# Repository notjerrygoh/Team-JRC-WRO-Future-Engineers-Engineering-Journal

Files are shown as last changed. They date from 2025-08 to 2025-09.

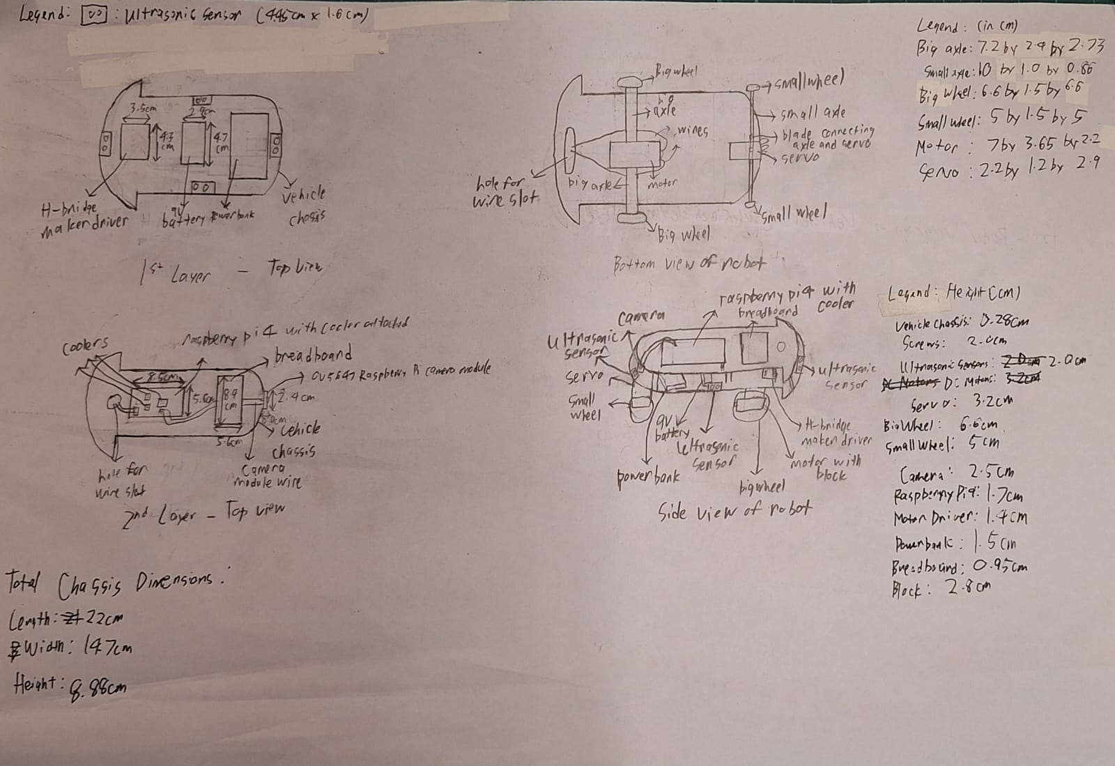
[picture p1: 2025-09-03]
mobility-management/Team JRC Robot Mechanical Diagram.jpeg

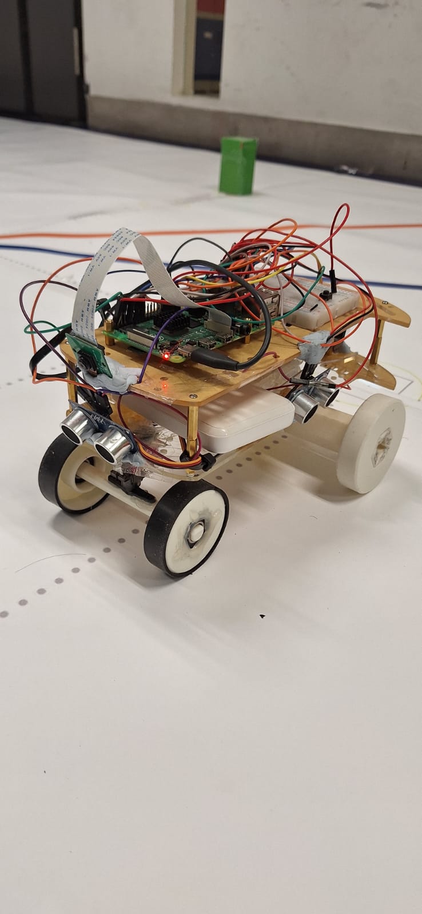
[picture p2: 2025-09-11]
v-photos/JRC's vehicle.jpeg

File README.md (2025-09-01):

Team JRC's Engineering Journal
====

Hello! We are team JRC, consisting of Jeremiah, Colin and Rey from Ngee Ann Polytechnic. We are participating in the World Robot Olympiad (WRO) Future Engineers competition in the season 2025. This repository contains engineering materials of the automated vehicle's model, as well as our engineering journal, where we document our experiences and the engineering design process even as we design and build our robot.

## Content

* `t-photos` contains 2 photos of the team (an official one and one funny photo with all team members)
* `v-photos` contains 6 photos of the vehicle (from every side, from top and bottom)
* `video` contains the video.md file with the link to a video where driving demonstration exists
* `schemes` contains one or several schematic diagrams in form of JPEG, PNG or PDF of the electromechanical components illustrating all the elements (electronic components and motors) used in the vehicle and how they connect to each other.
* `src` contains code of control software for all components which were programmed to participate in the competition
* `models` is for the files for models used by 3D printers, laser cutting machines and CNC machines to produce the vehicle elements. If there is nothing to add to this location, the directory can be removed.
* `mobility-management` contains the discussion for mobility management on how the motors are selected and implemented into our vehicle, as well as the vehicle chassis design selection and how the components are mounted onto the vehicle.
* `power-and-sense-management` contains the discussion for power and sense management on how the different power supply sources, as well as the sensors to detect objects are selected and implemented into our vehicle.
* `obstacle-management` contains the discussion for obstacle management on the vehicle's logic when it comes to avoiding obstacles and parking, and contains files of the pseudocode.
* `other` is for other files which can be used to understand how to prepare the vehicle for the competition. It may include documentation how to connect to a SBC/SBM and upload files there, datasets, hardware specifications, communication protocols descriptions etc. If there is nothing to add to this location, the directory can be removed.

## Introduction
The code consists of the following segments:
1. Colour Detection
2. Servo Movement
3. DC motor movement
4. Object detection
5. Line detection
6. Parking

### Basic functions
#### Colour detection
The robot will detect the colours by the Pi camera that is attached to the Raspberry Pi. It does this by first giving it a predefined upper and lower limit of values in HSV (Hue, Saturation, Value) so that the Pi camera can use these values to create a range and eventually a mask to help detect the colours when given a frame captured.

#### Servo movement
The servo will move by using PWM by sending a signal through the connected GPIO pin. The servo, given the PWM value, would turn in either the clockwise and anticlockwise direction from the starting position.

#### DC motor Movement
The DC Motor uses a motor driver to drive the DC Motor with an external power supply (9V battery) as the 5V from the Raspberry Pi is not enough to sustain it. We will connect the motor driver to 2 pins, 23 and 24. GPIO pins 23 and 24 connect to M1A and M1B respectively, allowing the robot to move forwards and backwards given values entered into the code.

### Applications
#### Object Detection
This applications combines the colour detection with the servo movement. When the Pi Camera approaches the red or green block on the map, it will detect the colour of the incoming block by the Pi Camera and the servo would then perform a series of turns in order to avoid the obstacle by using PWM values. One such example is as follows:
If green block detected: 1000 (Turn Left) --> 1500 (Stabilise) --> 2000 (Turn Right) ---> 1500 (Stabilise) 

This helps the robot to avoid bumping into the obstacle in front all while moving forward

#### Line Detection
This application combines the colour detection as well as the servo movement. When the Pi Camera approaches an orange line, it will detect the orange line and then perform a series of maneuvres to turn. 
If orange line detected: Continue moving for 2 seconds (This is to ensure that the robot crosses the line) --> 1000 (for 2 seconds) --> 1500 (resume original position)

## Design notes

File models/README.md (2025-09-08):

# Models

This directory contains the files for models used by 3D printers and laser cutting machines to produce the vehicle elements.

## 3D Printed Elements:
1. Front wheel
2. Back wheel
3. Front axle
4. Back Axle
5. Block to hold motor (ensures that front and back wheels are leveled)

## Laser Cutting Elements:
1. Motor and Back Axle connector

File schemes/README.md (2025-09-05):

# Electromechanical diagrams
This directory must contain one or several schematic diagrams in form of JPEG, PNG or PDF of the electromechanical components illustrating all the elements (electronic components and motors) used in the vehicle and how they connect to each other.

## Refer to Team JRC Robot Schematic Diagram (LT Spice Software) for the original file of the schematic diagram
Download LT Spice in order to open the file.

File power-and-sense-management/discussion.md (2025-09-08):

# Power and sense management

## Power management
### Powerbank
For the power source of the robot, we have opted to use a power bank to power the Raspberry Pi 4, by using a USB-C cable to connect the power bank to the Raspberry Pi 4. This is because it has enough power to supply the Raspberry Pi 4 (which requires 15W (15 watts) for the Raspberry Pi 4 to run), unlike a battery, which does not supply enough power for the Raspberry Pi 4 to run.

### 9V battery
After much consideration, we also decided to add a 9V (9-volt) battery to supply the H-Bridge Motor Driver, as the Raspberry Pi 4 alone consumes lots of power from the power bank, and the power bank might not have enough power left to operate the H-Bridge Motor Driver, since it is connected in series. Hence, we decided to use a 9V battery to supply power to the Motor Driver for its operation, so that it will be able to drive the motors of the vehicle.

## Sense Management
### Ultrasonic Sensors
To complete the challenge, we have selected the HC-SR04 Ultrasonic sensor to detect obstacles that are around the vehicle while it is running. The ultrasonic sensors are used because they are inexpensive compared to other types of sensors, and because we can easily determine the distance from the vehicle to the object using the following formula:
                                      
                                                   d = t * 0.034 / 2
    where, 

      d: distance between the object and the vehicle's ultrasonic sensor (in metres)
      
      t: time taken from the time when the ultrasonic sends out pulses of ultrasonic waves from the echo pin and from the
         time that the ultrasonic receives the pulses from the trigger pin (in seconds)

This formula will help us in determining the distance of the vehicle from the object, and is vital in ensuring that the vehicle will avoid the obstacles as it moves around the circuit, which will be further discussed in the obstacle management section.

### Pi Camera
The Pi Camera is used as the main navigation tool of the robot. The robot will use the pi camera to detect the colour of the blocks and the lines to decide which direction to move in by turning the servo accordingly. It does this by first initialising the camera in 640 x 360 resolution. This is to help the pi process every frame captured by the camera for classification quickly and effectvely. Every frame is captured in an numPy array and each frame is inverted for processing as the default configuration for the Pi camera is the frame not being upright, which can affect data processsing. We will be using OpenCV to help detect the colours in each frame, which is why we convert each frame from RGB to BGR as OpenCV only accepts data in BGR format for processing. 

After detecting each frame, we will convert them into the HSV format to separate colour information (Hue) from intensity (Value) and saturation (Saturation) and make recognising objects much easier in varying lighting conditions. This is to help our robot be able to prepare for the change in lighting conditions on competition day. Once done, we will define the HSV range for each colour we are detecting (E.g Orange and Pink), with a lower and upper limit so that we can detect a range of colours in the case that our shade of selectred colours when doing testing is not the same shade during the competition. These values are found through online research as well as during testing. Using the upper and lower limits, we will then create a mask for each colour, highlighting only the pixels in that range. These masks created will then be cleaned with dilation and analyzed using contour detection to find the size and position of the colored regions and identify the colours present in the frame. This will help the robot to perform the relevant logic based on the colours detected. Examples include orange signals a lap line and increments the lap counter, pink indicates a parking zone which helps the robot position itself for parking.

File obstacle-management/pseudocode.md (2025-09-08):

START

FROM gpiozero IMPORT DistanceSensor
FROM gpiozero.pins.pigpio IMPORT PiGPIOFactory
FROM time IMPORT time
IMPORT pigpio
IMPORT numpy
IMPORT cv2
FROM picamera2 IMPORT Picamera2

INITIALISE pigpio library and assign to "pi"
INITIALISE GPIO pin factory and assign to "factory"

frontultrasonic = Reads ultrasonic sensor distance for the ultrasonic sensor on the left with GPIO pin 27 as echo and GPIO pin 22 as echo
leftultrasonic = Reads ultrasonic sensor distance for the ultrasonic sensor on the left with GPIO pin 17 as echo and GPIO pin 4 as echo
rightultrasonic = Reads ultrasonic sensor distance for the ultrasonic sensor on the left with GPIO pin 5 as echo and GPIO pin 6 as echo
backultrasonic = Reads ultrasonic sensor distance for the ultrasonic sensor on the left with GPIO pin 19 as echo and GPIO pin 26 as echo

servo_pin = GPIO pin 16
SET GPIO pin 18 connected to the servo as output pin
SET PWM signal on servo_pin with a frequency of 50 Hz 
SET PWM of servo_pin to 1500

INITIALISE Picamera and a preview with a resolution of 640 x 360

M1A = GPIO pin 23
M1B = GPIO pin 24
SET M1A as output pin using pigpio
SET M1B as output pin using pigpio

FUNCTION detect_orange(frame, on_orange_line, lap_count):
  CAPTURE a frame from the webcam and convert the frame from BGR to HSV (Hue, Saturation, Value) colour format (Makes it easier to detect colours)
  DEFINE lower/upper HSV limits for orange:
    orange_upper = H: 5, S: 150, V: 150
    orange_lower = H: 20, S: 255, V: 255
  orange_mask = Creates a mask that contains only pixels within the orange range (orange_upper, orange_lower)
  roi = Bottom 60 pixels of the orange_mask given the height and width
  orange_pixels = The number of non-zero pixels in roi identified
  
  crossed = False
  IF orange_pixels > 1000:
    IF NOT on_orange_line:
      lap_count += 1
      crossed = True
      on_orange_line = True 
    ELSE:
      on_orange_line = False
    ENDIF
  ENDIF

  contours, _ = Find all of the contours in orange_mask
  IF contours:
    largest = The contour with the largest area
    IF largest > 300:
      x, y, w, h = Get bounding rectangle of largest contour as (x, y, w, h)
      DRAW a rectangle on the frame at (x, y, x + w, y + h) in orange color
      ENDIF
  ENDIF

RETURN lap_count, on_orange_line, crossed
      
FUNCTION traffic_lights(frame):
  CAPTURE a frame from the webcam and convert the frame from BGR to HSV (Hue, Saturation, Value) colour format (Makes it     easier to detect colours)
  DEFINE lower/upper HSV limits for red:
    red_lower1 = H: 0, S: 150, V: 50
    red_upper1 = H: 5, S: 255, V: 255
    red_lower2 = H: 172, S: 150, V: 100
    red_upper2 = H: 180, S: 255, V: 255
  red_mask = Creates a mask that contains only pixels from both ranges (red_lower1, red_upper1) and (red_lower2, red_upper2)

  DEFINE lower/upper HSV limits for red:
    green_lower = H: 35, S: 50, V: 50
    green_upper = H: 85, S: 255, V: 255
  green_mask = Creates a mask that contains only pixels within the green range (green_lower, green_upper)

  kernel = Create a 5x5 matrix
  red_mask = Dilates the red_mask 
  green_mask = Dilates the green_mask

  FUNCTION detect_and_label(mask, color_bgr, label):
    contours, _ = Find all of the contours in mask
    IF NOT contours:
      RETURN 0, None
      ENDIF
    largest = The contour with the largest area
    area = The largest area
    IF 30000 < area < 60000:  
      x, y, w, h = Get bounding rectangle of largest contour as (x, y, w, h)
      DRAW a rectangle on the frame at (x, y, x + w, y + h) in orange color
      RETURN area, label
      ENDIF
    RETURN 0, None
  
  red_area, red_label = detect_and_label(red_mask, (0, 0, 255), "Red")
  green_area, green_label = detect_and_label(green_mask, (0, 255, 0), "Green")
  RETURN red_area, green_area, red_label, green_label

FUNCTION motorSpeed(speed):
  IF speed > 0:
    PWM Dutycycle of M1A = speed
    PWM Dutycycle of M1B = 0
  ELSEIF speed < 0:
    PWM Dutycycle of M1A = 0
    PWM Dutycycle of M1B = absolute value of speed
  ELSE:
    PWM Dutycycle of M1A = 0
    PWM Dutycycle of M1B = 0
  ENDIF

lap_count = 0
on_orange_line = False
orange_sequence = None  
servo_sequence = None  
stable_counter = 0 

WHILE True:
  frame = Capture frame from the PiCamera while converting the frame from RGB to BGR and also inverting the frame
  distance_cm = Distance detected by the frontultrasonic * 100
  current_time = time()
  IF lap_count < 12:
    lap_count, on_orange_line, crossed = detect_orange(frame, on_orange_line, lap_count)
    motorSpeed(100)
    IF crossed and orange_sequence is None:
      orange_sequence = ([(1500, 1.5), (2000, 1), (1500, 0)], steps = 0, current_time) (Servo PWM value, duration to hold)
      OUTPUT lap_count
    ENDIF
    IF orange_sequence is not None:
      steps, step_index, start_time = orange_sequence
      pos, duration = steps[steps_index]
      SET servo PWM value on servo_pin to be pos
      IF current_time - start_time >= duration:
        step_index += 1
        IF step_index >= len(steps):
          orange_sequence = None
        ELSE:
          orange_sequence = (steps, step_index, current_time)
        ENDIF
      ENDIF
    ENDIF
    IF orange_sequence is None:
      red_area, green_area, red_label, green_label = traffic_lights(frame)
      IF red_area > green_area or green_area > red_area:
        stable_counter += 1
      ELSE:
        stable_counter = 0
    IF servo_sequence is None and stable_counter >= 3:  
      IF red_area > green_area:
        servo_sequence = ([(2000,1), (1500,1), (1000,1), (1500,0)], 0, current_time + 0.1)
        color_detected = red_label
      ELSEIF green_area > red_area:
        servo_sequence = ([(1000,1), (1500,1), (2000,1), (1500,0)], 0, current_time + 0.1)
        color_detected = green_label
      ELSE:
        SET servo PWM value on servo_pin to be 1500
        color_detected = "None"
      ENDIF
    ELSEIF servo_sequence is not None:
        steps, step_index, start_time = servo_sequence
        pos, duration = steps[step_index]
        SET servo PWM value on servo_pin to be pos
        IF current_time - start_time >= duration:
          step_index += 1
          IF step_index >= len(steps):
              servo_sequence = None
          ELSE:
              servo_sequence = (steps, step_index, current_time)
          ENDIF
      color_detected = red_label IF red_area > green_area else green_label
    ELSE:
      color_detected = "None"
    ENDIF
    OUTPUT colour_detected
    cv2.imshow("Color Detection", frame)
 
 ELSE: #Parking logic here
  IF distance_cm < 30 and orange_sequence is None:
      SET servo PWM value on servo_pin to be 1500
      left_dist = leftultrasonic.distance * 100
      right_dist = rightultrasonic.distance * 100
      if left_dist > right_dist and left_dist > 20:
          SET servo PWM value on servo_pin to be 1000
      elif right_dist > left_dist and right_dist > 20:
          SET servo PWM value on servo_pin to be 2000
      else:
          SET servo PWM value on servo_pin to be 1500
          motorSpeed(0)

  IF cv2.waitKey(10) & 0xFF == ord('q'):
    motorSpeed(0)
    ENDWHILE

motorSpeed(0)
pwm.set_servo_pulsewidth(servo_pin, 0)
cv2.destroyAllWindows()
END

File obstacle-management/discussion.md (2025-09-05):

# Obstacle Management

## Ultrasonic Sensor
The ultrasonic sensor will send out pulses of ultrasonic waves when power is supplied to the ultrasonic sensor and record the time when it sends the ultrasonic waves. When the ultrasonic waves hit an object, it reflects towards the ultrasonic sensor, and the ultrasonic sensor will then receive the pulses of ultrasonic waves and record the time when it received the ultrasonic waves. Then, the program will calculate the total time taken for the ultrasonic waves to travel from the vehicle's ultrasonic sensor to the object and back using the formula taken from the Power and Sense Management Section:
                                                  
                                                   d = t * 0.034 / 2
    where, 

      d: distance between the object and the vehicle's ultrasonic sensor (in metres)
      
      t: time taken from the time when the ultrasonic sends out pulses of ultrasonic waves from the echo pin and from the
         time that the ultrasonic receives the pulses from the trigger pin (in seconds)
         
This formula will determine an approximate distance of the vehicle from the object. Within the code, there is a certain threshold value, which is the maximum distance that the vehicle can be from the object. If the distance between the vehicle and the object is less than this threshold value, then the vehicle will steer to the left or to the right depending on the colour of the block.

## Pi Camera
The Pi Camera is used as the main navigation tool of the robot. The robot will use the pi camera to detect the colour of the blocks and the lines to decide which direction to move in by turning the servo accordingly. It does this by first initialising the camera in 640 x 360 resolution. This is to help the pi process every frame captrured by the camera for classification quickly and effectvely. Every frame is captured in an numPy array and each frame is inverted for processing as the default configuration for the Pi camera is the frame not being upright, which can affect data processsing. We will be using OpenCV to help detect the colours in each frame, which is why we convert each frame from RGB to BGR as OpenCV only accepts data in BGR format for processing. 

After detecting each frame, we will convert them into the HSV format to separate colour information (Hue) from intensity (Value) and saturation (Saturation) and make recognising objects much easier in varying lighting conditions. This is to help our robot be able to prepare for the change in lighting conditions on competition day. Once done, we will define the HSV range for each colour we are detecting (E.g Red, Green), with a lower and upper limit so that we can detect a range of colours in the case that our shade of selectred colours when doing testing is not the same shade during the competition. These values are found through online research as well as during testing. Using the upper and lower limits, we will then create a mask for each colour, highlighting only the pixels in that range. These masks created will then be cleaned with dilation and analyzed using contour detection to find the size and position of the colored regions and identify the colours present in the frame. This will help the robot to perform the relevant logic based on the colours detected. An example of this is how the camera picks up the red and green colours from the blocks to control servo sequences to allow the robot to avoid the coloured blocks.

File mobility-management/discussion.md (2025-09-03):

# Mobility Management
This file contains the discussion of how we chose the motors and servos used for the robot and implemented them into the robot, as well as how the vehicle chassis design was chosen and the assembly process of the vehicle

## Driving Mechanism

### Using Servos to turn the vehicle
During the planning and design phases, we decided as a team to create a back-wheel drive car, with the two front wheels used to steer the vehicle left and right, and the rear two wheels used to drive the vehicle forward and backwards. As a team, we decided to use a 180 degree 12 gram servo (MG90S) as part of the steering mechanism, as the servo was not only lightweight (12 grams), but because when 4.8V is supplied to the motor, assuming there is no load, the servo had a fast speed of 60 degrees for every 0.1 seconds, which is approximately 327 rpm (revolutions per minute). The servo also produces a torque of 1.8 kg.cm, which is approximately 0.1765 N.m (newton-meters). Thus, by using the following formula:
                                     
                                  power = speed (rpm) * 2π * torque (Nm) * efficiency (%)
                                              
Therefore, assuming 80% efficiency when the servo turns to the left and the right (since servo might have wear and tear and lose its efficiency over time, and since the servo is also attached to the axle and the wheels and has to turn the entire vehicle, which contributes to its load), we were able to derive the power generated by the servo as the servo turns the axle at a certain angle. From our calculations, we determined that since the servo turns 45 degrees when turning to the left of the right, it will take approximately 0.075 seconds (approximately 100.2 rpm) to turn to the left of the right. Thus, using the formula, the power generated by the servo is 88.9 W (watts) per turn, which is more than enough to power the servo to turn to the left and to the right, which allows the axle to turn the wheels to the left and right without encountering much difficulties turning the vehicle.

### Using Motors to drive the vehicle
We also decided to use a 5V (5 volt) DC (direct current) motor to drive the vehicle, as DC motors have an infinite turning range, thus being able to drive the vehicle for long durations. However, since the DC motors have a large operating voltage and current, we also used a H-bridge Motor Driver to drive the motors so that it will be able to drive the vehicle to move forwards and backwards, as without the driver, the motors would not be able to operate by only using a raspberry pi 4, since its operating voltage is higher than the output voltage which the raspberry pi 4 can provide to the motors.
uu
## Vehicle Chassis Assembly
### Step 1: Designing Phase
When designing the robot, we decided to go for our current design of the vehicle chassis, the 2WD robot chassis, made out of acrylic material, and purchased it online through an e-commerce platform, as it is lightweight (insert the weight of the chassis without any components) and we originally thought that the design was spacious enough for us to mount our components, which are the motors, servos, ultrasonic sensors and cameras, our microcontroller, the Raspberry Pi 4 and the power supplies, which are our 9V battery and power bank.

### Step 2: Vehicle Frame Assembly
When assembling the vehicle together, we considered the amount of space that we needed for the motors, servos, ultrasonic sensors and cameras, our microcontroller, the Raspberry Pi 4, the breadboard and the power supplies, which are our 9V battery and power bank. We realised that our current design would not be able to fit all the components together, and using a bigger chassis would exceed the competition limit of 30 by 20 cm for the vehicle chassis. Thus, to resolve the problem, we decided to have a second layer with the exact same design as the first layer and connected it together using screws, which will give enough space for the components to be mounted onto the vehicle chassis. We attached 2 screws at the front of the vehicle chassis, another 2 screws at the back of the vehicle chassis and finally 1 screw at the middle of the vehicle chassis, which will be able to support the weight of the components on the 2nd layer. 

### Step 3: Back-Wheel Assembly Process
*TODO: Add images for clarity*

The requirement of having both wheels driven by the same motor meant that the motor needed to be placed in the centre of the robot. Having the wheels attached to the motor would require the wheels to be almost next to each other, like dual wheels, as the motor's built-in axle was very small, which would affect the robot's stability. To resolve this, we designed and 3D printed custom-made axles, which were longer and bigger in size, and custom-made wheels, with its dimensions similar to the original wheels, which we were intending on using with a few modifications to attach our new axle to the wheel.

To attach the wheels and the axle together in place, we 3D printed the wheels to have a hexagonal-shaped hole at its centre, which allowed the hexagonal-shaped axles to fit nicely through the hole. This ensured that the axles were secured well into the wheels, which in turn ensured that the wheels would not fall off as easily. We then attached the axle to the DC motor by 3D printing connectors of the same size as the axle so that the axle would fit snugly with the DC motor.

### Step 4: Front-Wheel Designing and Assembly Process
Since our robot was driven by only the back wheels, our front wheels had to be free-wheeling. We used ball bearings, which fit in the centre of the front wheels to let them spin freely, and printed an axle to connect the wheels. This axle is rotated by a servo motor facing downwards to provide steering.

The ball bearings needed to be small enough to fit the front wheels, which had the same size as the back wheels, 66mm in diameter, but they also could not be so small that the axle connecting the wheels would be too thin and weak to hold up the robot. We chose metal ball bearings with a 22mm outer diameter, 10mm inner diameter and 8mm in depth as an inexpensive ball bearing.

Additionally, we also 3D-printed our front wheels, which were custom-made to attach the ball bearings to the wheels and were smaller than the back wheels, which ensured that the wheels were lighter and made the process of turning the vehicle much smoother. We also 3D-printed our axle, shaped like a cylinder with a smooth flat surface at the top. Our axle has a diameter of 10mm  to ensure that both front wheels are well spaced apart from each other.

Finally, we hot-glued the axle to the servo blade and attached the servo blade to the servo. This ensured that when the servo turns, the axle would turn as well, allowing the vehicle to steer in different directions when encountering obstacles.

### Step 5: Final Vehicle Assembly (Mounting components onto the vehicle)
We decided to place the ultrasonic sensors, H-bridge motor driver, the powerbank and the 9V battery on the first layer (bottom) and the Raspberry Pi 4, breadboard and camera on the second layer (top). We also decided to place the servo and motor at the bottom of the vehicle, with the servo attached to our 3D-printed axle and wheels, and the motor attached to another custom-made 3D-printed axle and wheels. (Refer to the Mechanical Diagram of the Vehicle). We utilised the mini holes in our vehicle chassis to organise our wires within the slots, which would make it easier to troubleshoot and move components within the vehicle, and used cable ties to tie our wires together, which would allow the wires not to be dangling when the vehicle was moving.

### Vehicle Assembly Considerations
A consideration we took when assembling the vehicle together was the weight of each component. An example of this is how we decided to place our powerbank in the first layer in the middle of the vehicle since that was where the vehicle's centre of gravity lies at and because we did not want to shift the vehicle's centre of gravity. We then distributed the remaining components evenly to balance the weight. Another consideration we took was the function and purpose of each component. For instance, we placed the ultrasonic sensors on the first layer in order to detect if there were any walls in the surroundings and for parking. Moreover, we also placed the camera on the second layer as we wanted it to detect for the objects around it and the lines more effectively, since it will have a better view of its surroundings compared to when it is placed in the first layer.

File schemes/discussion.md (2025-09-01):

# Raspberry Pi
We chose to use the Raspberry Pi as the central controller for our robot because it can be a microcontroller and a microprocessor at the same time. This allows us to conserve space on the robot as we do not need an additional Arduino to control the various sensors on the robot and it also makes it easier for us to troubleshoot if there are any issues during testing as we are only dealing with one system instead of 2. The Raspberry Pi is equipped with a Pi Camera slot, which helps in the computer vision of the task. On top of that, the Raspberry Pi also has GPIO (General Purpose Input Output) pins to connect different periphrals for different applications. In this case, we will be using the GPIO pins to connect hardware such as the ultrasonic sensors, servos and DC Motors.

## Ultrasonic Sensors
For the ultrasonic sensors, we will define the following pins:
Front ultrasonic sensors (Echo: 27, Trigger: 22)
Back ultrasonic sensors (Echo: 19, Trigger: 26)
Left ultrasonic sensors (Echo: 17, Trigger: 4)
Right ultrasonic sensors (Echo: 5, Trigger: 6)

The ultrasonic sensors will then detect and calculate the distances between itself and the object and produce the calculated distance as output. This value is then read through the pi by gpiozero library with the pigpio backend.

## Servo
Using the distances detected by the ultrasonic sensors, the Pi will then activate the servo connected to GPIO pin 16 of the Raspberry Pi. The servo will be driven by PWM (Pulse-width modulation) to move at the different angles to evade the obstacles detected by thu ultrasonic sensors. When the Pi Camera detects a certain colour, it will also activate the servo motor via GPIO pin 16 to move in the different directions.

## DC Motors
The DC Motors are connected to the Raspberry Pi via a motor driver. The motor driver is there to help regulate the motor's speed, direction to ensure reliable and efficient operation. The motor driver requires 2 pins, therefore, we will be using 2 pins:
M1A: 23
M1B: 24

Both M1A and M1B are controlled via PWM duty cycles, allowing the robot to move forward, backward, or stop with varying speeds.

## Pi Camera
The PiCamera is connected physically to the Picamera slot in the Raspberry Pi, accessed through the Picamera2 library, captures live video frames, which are processed with OpenCV to detect colors: orange lines for lap counting, pink for parking zones, and red/green the coloured blocks. Each detection routine converts the frame to HSV, applies color thresholds, cleans up masks, and uses contours to decide whether a target color is present and how the robot should respond.

All these feed into the main loop: the Raspberry Pi continuously reads camera frames and ultrasonic distances, decides what situation the robot is in (lap crossing, obstacle detection or parking), and then sends PWM commands to the motors and servo to execute the correct action.

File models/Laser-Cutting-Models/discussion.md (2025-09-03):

# Discussion

A few shapes were considered for the gears linking the motor's small axle and our 3D-printed axle.

## Main linking gear

An extension was needed to fit onto both the motor's axle and 3d-printed axle snugly and ensure both axles turned with each other. Options for the shape of this extension ranged from hexagons (like hex screws) to gears with many teeth. For the outer shape, we settled on a 4-point star-shaped gear based halfway between a Phillips and a Torx head. This shape was easy to model and had walls that were almost perpendicular to the turning motion, resulting in a very low chance of camming out.

For the inner shape, we followed the cross-sectional shape of the motor's axle. This was done by using a circle and introducing a chord in the circle to make the flat sides of the axle. Many rounds of trial and error were neeeded to perfectly match the size of the motor. Initially, a 5.2mm diameter circle with a 3.5mm wide top fit perfectly, but after a few weeks of laser cutting, we needed to adjust the diameter to 5.05mm and the width of the top to 3.4mm.

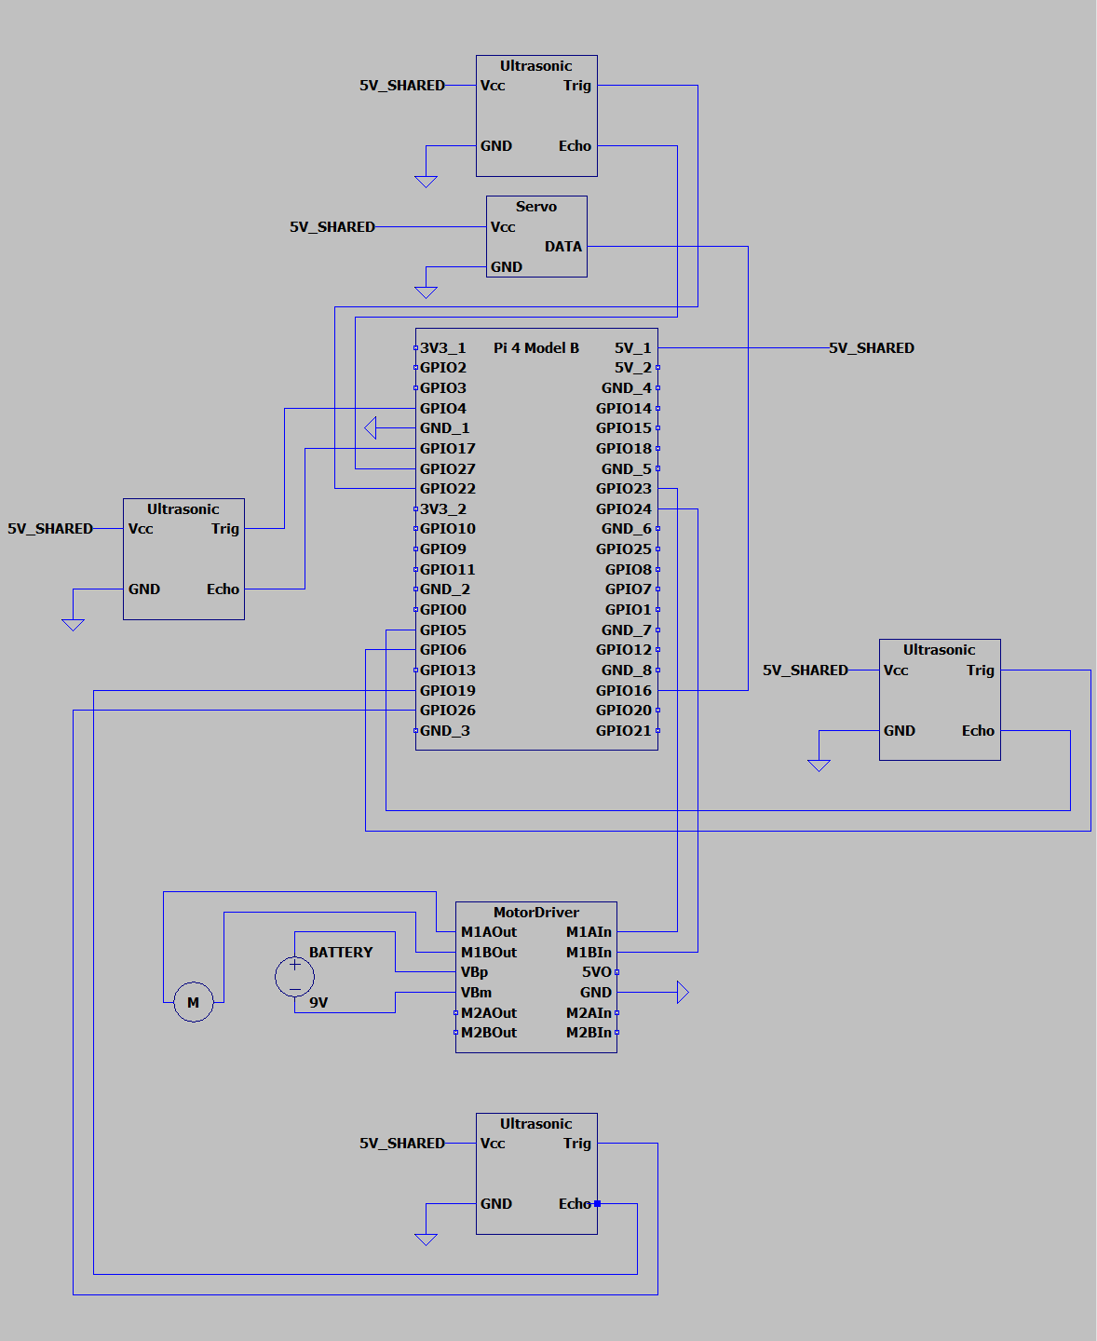
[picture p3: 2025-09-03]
schemes/Team JRC Robot Schematic Diagram.png

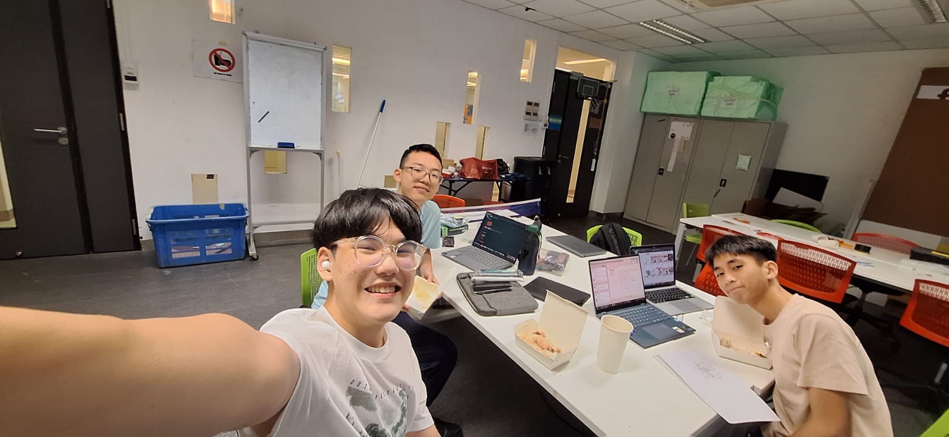
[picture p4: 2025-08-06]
t-photos/JRC Team Photo of First Meeting.jpeg

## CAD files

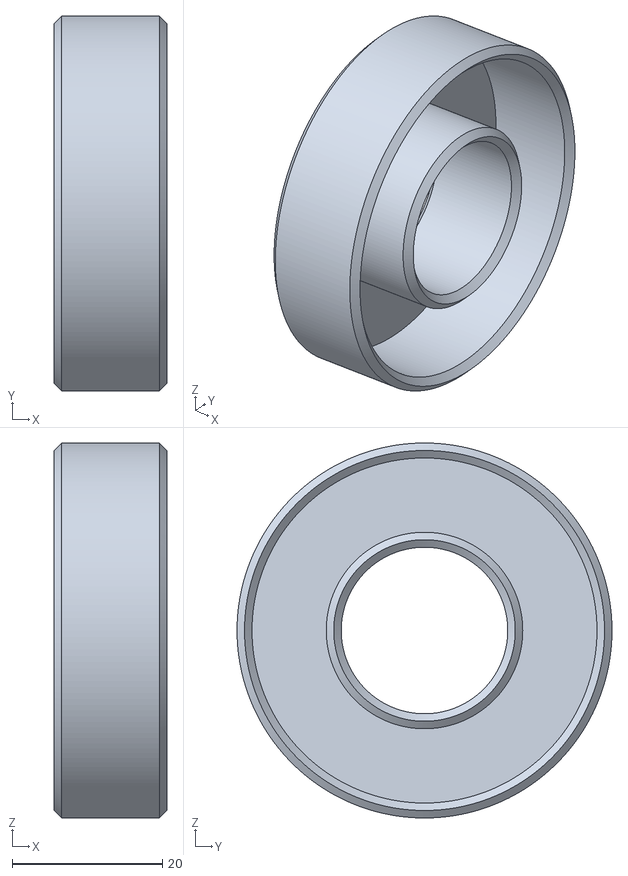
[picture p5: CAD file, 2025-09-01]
models/3D-Printed-Models/front wheels.stl
15.0 x 50.0 x 50.0

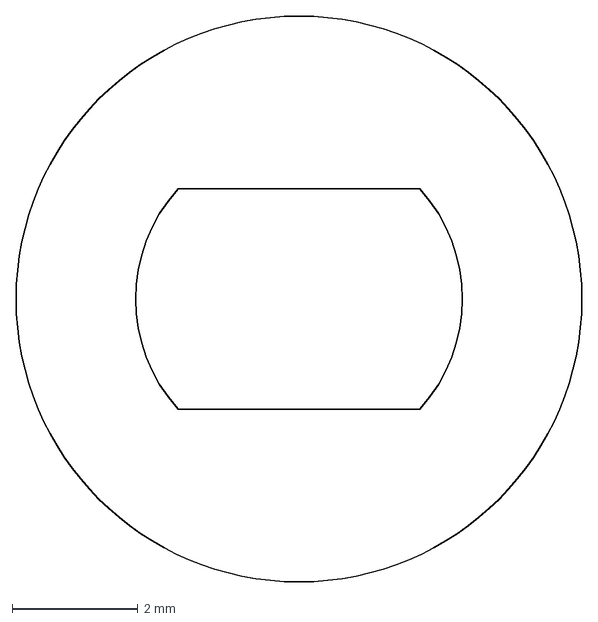
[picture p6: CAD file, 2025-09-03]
models/Laser-Cutting-Models/inner 3.5 x 5.2 circular spacer.dxf
9.00 x 9.00 mm

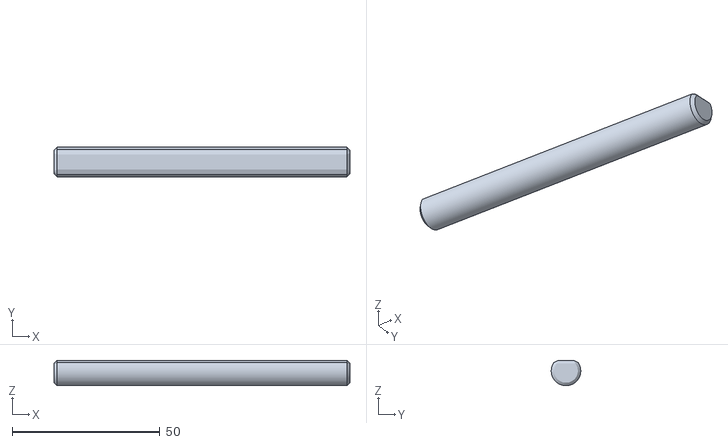
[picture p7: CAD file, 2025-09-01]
models/3D-Printed-Models/front axle.stl
100.0 x 10.00 x 8.57

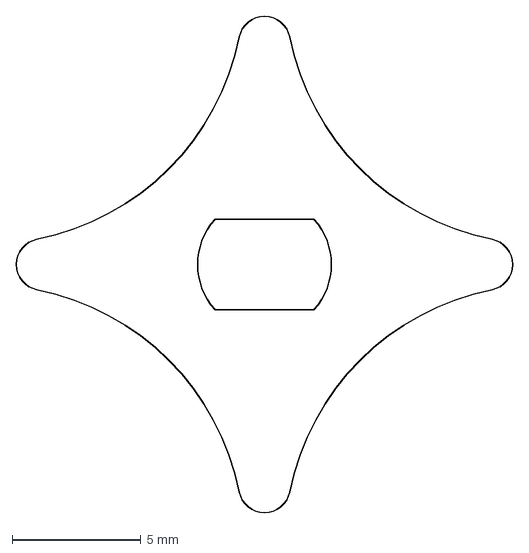
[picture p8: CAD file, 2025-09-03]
models/Laser-Cutting-Models/inner 3.5 x 5.2 star gear.dxf
19.3 x 19.3 mm

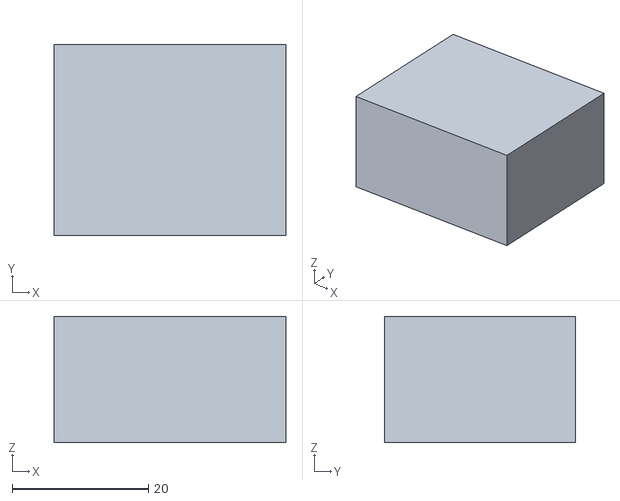
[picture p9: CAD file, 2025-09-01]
models/3D-Printed-Models/block for motor.stl
34.0 x 28.0 x 18.5

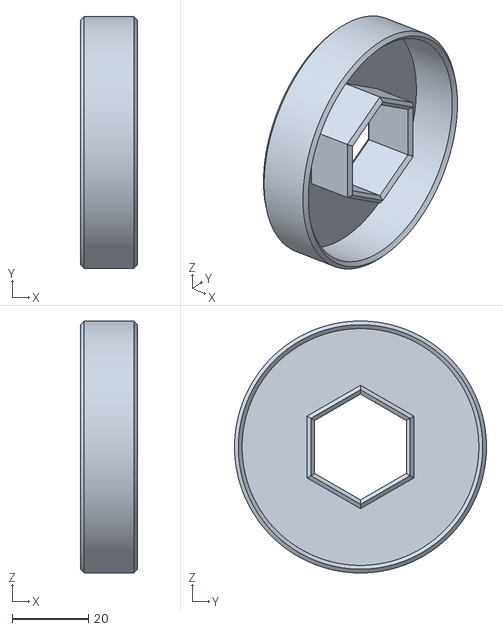
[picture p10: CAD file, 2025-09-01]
models/3D-Printed-Models/back wheels.stl
15.0 x 66.0 x 66.0

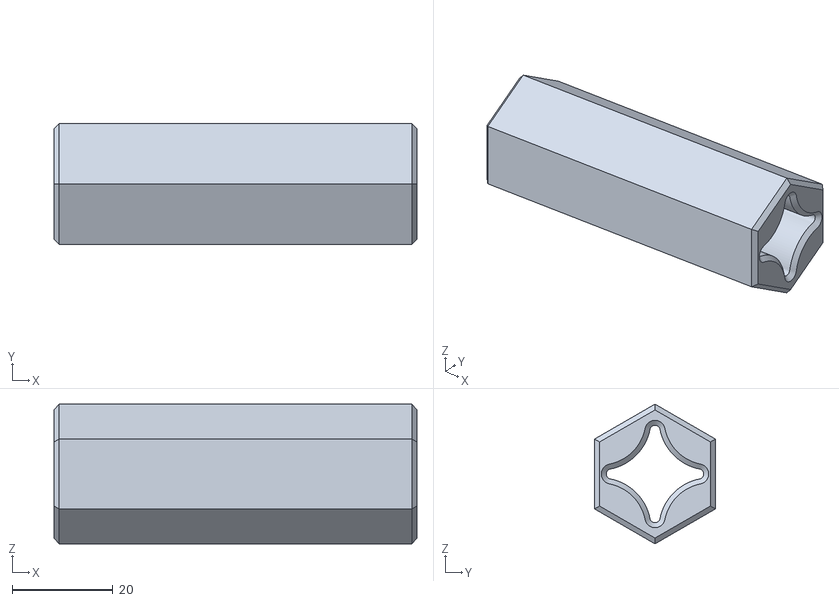
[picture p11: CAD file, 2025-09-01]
models/3D-Printed-Models/back axle.stl
72.0 x 24.0 x 27.7

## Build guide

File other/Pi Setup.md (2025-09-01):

# Initialising Operating system

Setup SD card
1. Buy an SD Card and an SD card Reader
2. Boot up a computer with a SD card reader available slot
3. Connect the purchased SD card to the computer via the SD card reader
4. Download Raspberry Pi Imager on your computer. You can install the latest version from raspberrypi.com/software and run the installer.
5. Once you’ve installed Imager, launch the application by clicking the Raspberry Pi Imager icon or running rpi-imager
6. Click Choose device and select your Raspberry Pi model from the list.
7. Next, click Choose OS and select an operating system to install. In this case, I used Raspberry OS (64-bit)
8. Connect your preferred storage device to your computer and select it by clicking on "Choose Storage" on the menu and searching for it 
9. When prompted with OS customisation settings, click on "Edit settings"
The OS customisation menu lets you set up your Raspberry Pi before first boot. You can preconfigure:
A username and password
Wi-Fi credentials
the device hostname
The time zone
Your keyboard layout
Remote connectivity
When prompted for permission to load Wi-Fi credentials from your host computer. Click "Yes". Imager will prefill Wi-Fi credentials from the network you’re currently connected to.

10. When you’ve finished entering OS customisation settings, click Save to save your customisation.
11. Click Yes to apply OS customisation settings when you write the image to the storage device.
12. Respond Yes to the "Are you sure you want to continue?" popup to begin writing data to the storage device.
13. When you see the "Write Successful" popup, your image has been completely written and verified. You’re now ready to boot a Raspberry Pi from the storage device.

# Initialising Raspberry Pi
1. Slot the SD Card into the SD Card slot on the Raspberry Pi
2. Plug in peripherals, such as your mouse, keyboard, and monitor.
3. Plug in the power cable. You should see the status LED light up when your Pi powers on. If your Pi is connected to a display, you should see the boot screen within minutes.
4. If the Raspberry Pi shows a desktop page, it is ready for use.

# Initialising Raspberry Pi Connect
1. Open terminal on desktop
2. Run the following commands:
sudo apt update
sudo apt full-upgrade
sudo apt install rpi-connect
rpi-connect on (This allows Raspberry Pi Connect to be activated)
4. Click on the Connect plugin for the menu bar
5. Click Turn On Raspberry Pi Connect for the first time to open your browser, prompting you to sign in with your Raspberry Pi ID. Create one if you haven't.
6. After authenticating, assign a name to your device. Choose a name that uniquely identifies the device. Click the Create device and sign in button to continue.
7. You can now remotely connect to your device. The Connect icon in your menu bar will turn blue to indicate that your device is now signed in to the Connect service. You should receive an email notification indicating that a new device is linked to your Connect account.

Connect includes the ability to share your device’s screen in a browser. Use the following instructions to share your device’s screen.

1. Connect redirects you to the Raspberry Pi ID service to sign in. After signing in, Connect displays a list of linked devices. Devices available for screen sharing show a grey Screen sharing badge below the name of the device
2. Click the Connect via button to the right of the device you would like to access. Select the Screen sharing option from the menu. This opens a browser window that displays your device’s desktop.
3. You can now use your device as you would locally.
4. A green dot appears next to the Screen sharing badge in the Connect dashboard. This indicates an active screen sharing session
5. The Connect icon in the system tray turns purple and displays a closed circle when a screen sharing session is in progress. A desktop notification will appear whenever a screen sharing session starts.
6. To close a screen sharing session, click the Disconnect button above your desktop

# Using Python on Raspberry Pi
1. In the main menu (click the raspberry icon), click on programming and then Geany Programmer’s Editor.
2. Open a python file from the menu of geany
3. Start coding

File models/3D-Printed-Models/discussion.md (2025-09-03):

# Discussion
## Back Axle Design
When designing the whole robot, we realised that the current motor that we were utilising had a very small diameter. However, the 3D printer was too imprecise to print a hole shaped like it, and thus we had to print new axles to extend the small axle of the motor by creating a hexagonal-shaped sleeve around the original axle. Therefore, we had to laser cut a gear that linked the motor's small axle and our larger axle sleeve together (see laser-cutting-models -> discussion.md). The wheels would then go on the ends of the large axles, which created a system for the motor to turn both wheels about the axles.

## Back wheels Design
Initially, our back wheels were the wheels that came with the kit that we bought along with the vehicle chassis. However, these wheels were meant to fit with the original small axle of the motor, and could not fit with our larger custom axle. Hence, we made these wheels the same size as the original wheels in diameter (66mm), while also adding a hexagonal-shaped hole at the very centre of the wheel, big enough to fit the back axle into the wheel. We also decided to 3D print the wheel to be 15mm in width, as it was the perfect size to allow the wheels to have just enough friction to drive the vehicle forward. 

## Front Axle Design
One of the considerations we took when designing the axle was that the axle could not be too small, such that the axle connecting the wheels would be too thin and weak to hold up the vehicle. The axle had to be firm enough to withstand the weight of the vehicle, while also not being too heavy, which might affect the vehicle's ability to turn. 

Thus, we designed the axle to be a 3D-printed cylinder with a 20% infill density, which ensured that the axle was thick and strong enough to withstand the weight of the vehicle. Additionally, we also designed the axle to have a diameter of 10mm to fit the ball bearings into the axle. 

The axle was also designed to be 100mm in length, which was decided after multiple rounds of testing. This ensured that the wheels were not too far apart and that the wheels and axles could be turned by the servo motor, while ensuring that the axle was not too long to reduce the required moment needed to turn the wheels.

## Front wheels Design
When designing the front wheels, we took into account the ball bearings, which had to be incorporated into the front wheels, allowing the front wheels to spin freely without rotating the axle, which was attached to the servo.

When designing the wheels, one of the key features that the wheel had to contain was that the front wheels needed to be large enough but not too large to fit the ball bearings into the wheels, as the ball bearings would allow the wheel to spin freely and we also wanted the ball bearings to be secured into the wheels without dropping out or moving around as much. Thus, we decided to design the wheels to have a circular hole at the centre measuring 22.2mm in diameter and 15 mm in width. This allowed the ball bearings to fit nicely into the front wheels of the car without movement.

For the wheel itself, while we were testing out different prints of wheels of different dimensions, we discovered that the servo was not able to turn at first, as the wheels were too large and heavy, preventing the servo from turning the vehicle left and right. We then realised that the front wheels had to be light so that they would allow the servo to be able to turn the axle to turn the wheels without much difficulty. 

Therefore, we designed the wheels to be 50mm in diameter and 25mm in width for the outer frame, with about 20% infill density, so that it would be able to maintain its shape while also being as light as possible, making the turning process smoother. We also decided to use PLA as the material for the wheels, as it was lightweight and easy to print. 

## Block for the motor
While assembling the vehicle together, we realised that the back wheels' and axles' diameter were both too tall, and as a result both the wheels and axles would collide into the vehicle's frame. As a result, we had 2 options: reprint smaller wheels and a smaller set of axles, or we could add a supporting block to increase the distance between the wheel and the vehicle's frame. We eventually decided to add a supporting block, as it was easier to print out rather than redesigning a whole new set of wheels and axles and also the connectors for the small axle and the big axle. We decided that the dimensions of the block would be identical to the motor's dimensions in terms of its length and width (28mm by 1.85mm), and designing the height of the block to be 34mm, which was the right size to ensure that the wheels and axles were at a reasonable distance from the vehicle's frame, thus eliminating the possibility of the vehicle's wheels and axles from coming into contact with the vehicle's frame.

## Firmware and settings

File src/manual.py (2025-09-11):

import pigpio
from time import sleep

import sys
import termios
import io

pi = pigpio.pi()
M1A = 23
M1B = 24

servo = 16

pi.set_mode(M1A, pigpio.OUTPUT)
pi.set_mode(M1B, pigpio.OUTPUT)
pi.set_mode(servo, pigpio.OUTPUT)
pi.set_PWM_frequency(servo, 50)

cspeed = 0
cdir = 0
crev = 0
cbrake = True
coffset = 300

def motorSpeed(speed):
    m1aspeed = 0
    m1bspeed = 0
    if (speed < 0):
        m1aspeed = -speed
    else:
        m1bspeed = speed

    try:
        pi.set_PWM_dutycycle(M1A, m1aspeed)
        pi.set_PWM_dutycycle(M1B, m1bspeed)
    except Exception as e:
        print(e)

def update():
    realspeed = 0 if cbrake else (-cspeed if crev else cspeed)
    motorSpeed(realspeed)
    pi.set_servo_pulsewidth(servo, 1500 + cdir * coffset)

print("current speed", cspeed)

def clamp(d, m, x):
    r = d
    if r < m:
        r = m
    if r > x:
        r = x
    return r

def handle(inp):
    global cspeed, cdir, crev, cbrake, coffset

    match inp:
        case " ":
            cbrake = not cbrake
        case "a":
            cdir -= 1
        case "d":
            cdir += 1
        case "s":
            crev = True
        case "w":
            crev = False
        case "1":
            cspeed = 0
        case "2":
            cspeed -= 10
        case "3":
            cspeed += 10
        case "4":
            cspeed = 100
        case "5":
            cspeed = 255
        case "[":
            coffset -= 50
        case "]":
            coffset += 50


    cspeed = clamp(cspeed, 0, 255)
    cdir = clamp(cdir, -1, 1)
    sdir = ["left", "straight", "right"][cdir + 1]
    sbf = ["forwards", "backwards"][int(crev)]
    sbr = ["(no brake)", "(brake)"][int(cbrake)]
    print(cspeed, "spd", sdir, sbf, sbr, coffset)

    update()
            

oldattr = termios.tcgetattr(sys.stdin.fileno())
newattr = oldattr[::]
newattr[3] &= ~termios.ICANON
newattr[3] &= ~termios.ECHO
termios.tcsetattr(sys.stdin.fileno(), termios.TCSANOW, newattr)


stdin = io.open(sys.stdin.fileno(), 'rb', closefd=False)

while True:
    try:
        handle(stdin.read(1).decode("utf-8"))
    except KeyboardInterrupt:
        termios.tcsetattr(sys.stdin.fileno(), termios.TCSANOW, oldattr)
        break

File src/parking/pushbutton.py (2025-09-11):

from gpiozero import Button
from time import sleep, time

button = Button(13, pull_up=True)  # enable internal pull-up

last_click = 0

def pressed():
    global last_click
    now = time()
    if now - last_click < 1:  # double press within 1 sec
        print("⏹ Double click detected → stop")
    else:
        print("▶ Single click → start")
    last_click = now

button.when_pressed = pressed

print("Waiting for button presses...")
while True:
    sleep(0.1)

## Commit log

2025-09-01 Update and rename models/10cm chamfered front axle.stl to models/3D-Printed-Models/10cm chamfered front axle.stl
    [10cm chamfered front axle.stl]
2025-09-01 Rename models/Block for Motor.stl to models/3D-Printed-Models/Block for Motor.stl
    [Block for Motor.stl]
2025-09-01 Update and rename models/chamfered back axle 2.stl to models/3D-Printed-Models/chamfered back axle 2.stl
    [chamfered back axle 2.stl]
2025-09-01 Update and rename models/chamfered back wheels 2.stl to models/3D-Printed-Models/chamfered back wheels 2.stl
    [chamfered back wheels 2.stl]
2025-09-01 Rename models/small wheel front chamfered.stl to models/3D-Printed-Models/small wheel front chamfered.stl
    [small wheel front chamfered.stl]
2025-09-01 Rename small wheel front chamfered.stl to front wheels
2025-09-01 Update and rename chamfered back wheels 2.stl to back wheels
2025-09-01 Update back wheels
2025-09-01 Rename front wheels to front wheels.stl
    [front wheels.stl]
2025-09-01 Update and rename back wheels to back wheels.stl
    [back wheels.stl]
2025-09-01 Update and rename chamfered back axle 2.stl to back axle.stl
    [back axle.stl]
2025-09-01 Update and rename 10cm chamfered front axle.stl to front axle.stl
    [front axle.stl]
2025-09-01 Rename Block for Motor.stl to block for motor.stl
    [block for motor.stl]
2025-09-01 back wheel and front wheel discussion (todo: add images)
2025-09-03 Update diagram and add laser cutting files Replaced diagram's zip file with a folder for ease of access.
    [inner 3.5 x 5.2 circular spacer.dxf, inner 3.5 x 5.2 star gear.dxf]
2025-09-03 Add discussion for laser cutting and why we chose a star shape
2025-09-10 add bluedetect add visual bars to centering (doesn't work now)
    [bluedetect.py]
